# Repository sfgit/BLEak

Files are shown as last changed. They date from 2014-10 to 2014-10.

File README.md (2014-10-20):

BLEak
=====

BLE + ATMega Kit

Meet BLEak - the BLE + ATMega Kit.  This is a board I'm building for a one-day workshop in San Francisco.  The board includes the NRF8001 + ATMega328-AUR (SMD, a'la Arduino SMD) and should include some basic SPI sensors / IO.  Existing Arduino SW libraries for the nrf8001 should work with BLEak.  The basis of the workshop is to show the transition from Arduino to a production PCB and BLEak is a nice narrative that mixes some simple wireless / RF with the ATMega in a module that just might be the prodcut someone is trying to build.  

LICENSE + NOTES:  (PLEASE READ)
This design is released under a Creative-Commons Share-alike, Attribution license.  You can use this design without needing to ask for permission from me.

The designer (me, the guy typing this) is furnishing this item "as is". The design does not provide any warranty of the item whatsoever, whether express, implied, or statutory, including, but not limited to, any warranty of merchantability or fitness for a particular purpose or any warranty that the contents of the item will be error-free.

In no respect shall the designer incur any liability for any damages, including, but limited to, direct, indirect, special, or consequential damages arising out of, resulting from, or any way connected to the use of the item, whether or not based upon warranty, contract, tort, or otherwise; whether or not injury was sustained by persons or property or otherwise; and whether or not loss was sustained from, or arose out of, the results of, the item, or any services that may be provided by the designer.

Be careful.  This is a work in progress.  You use this AT YOUR OWN RISK.  Electronics such as these can kill.

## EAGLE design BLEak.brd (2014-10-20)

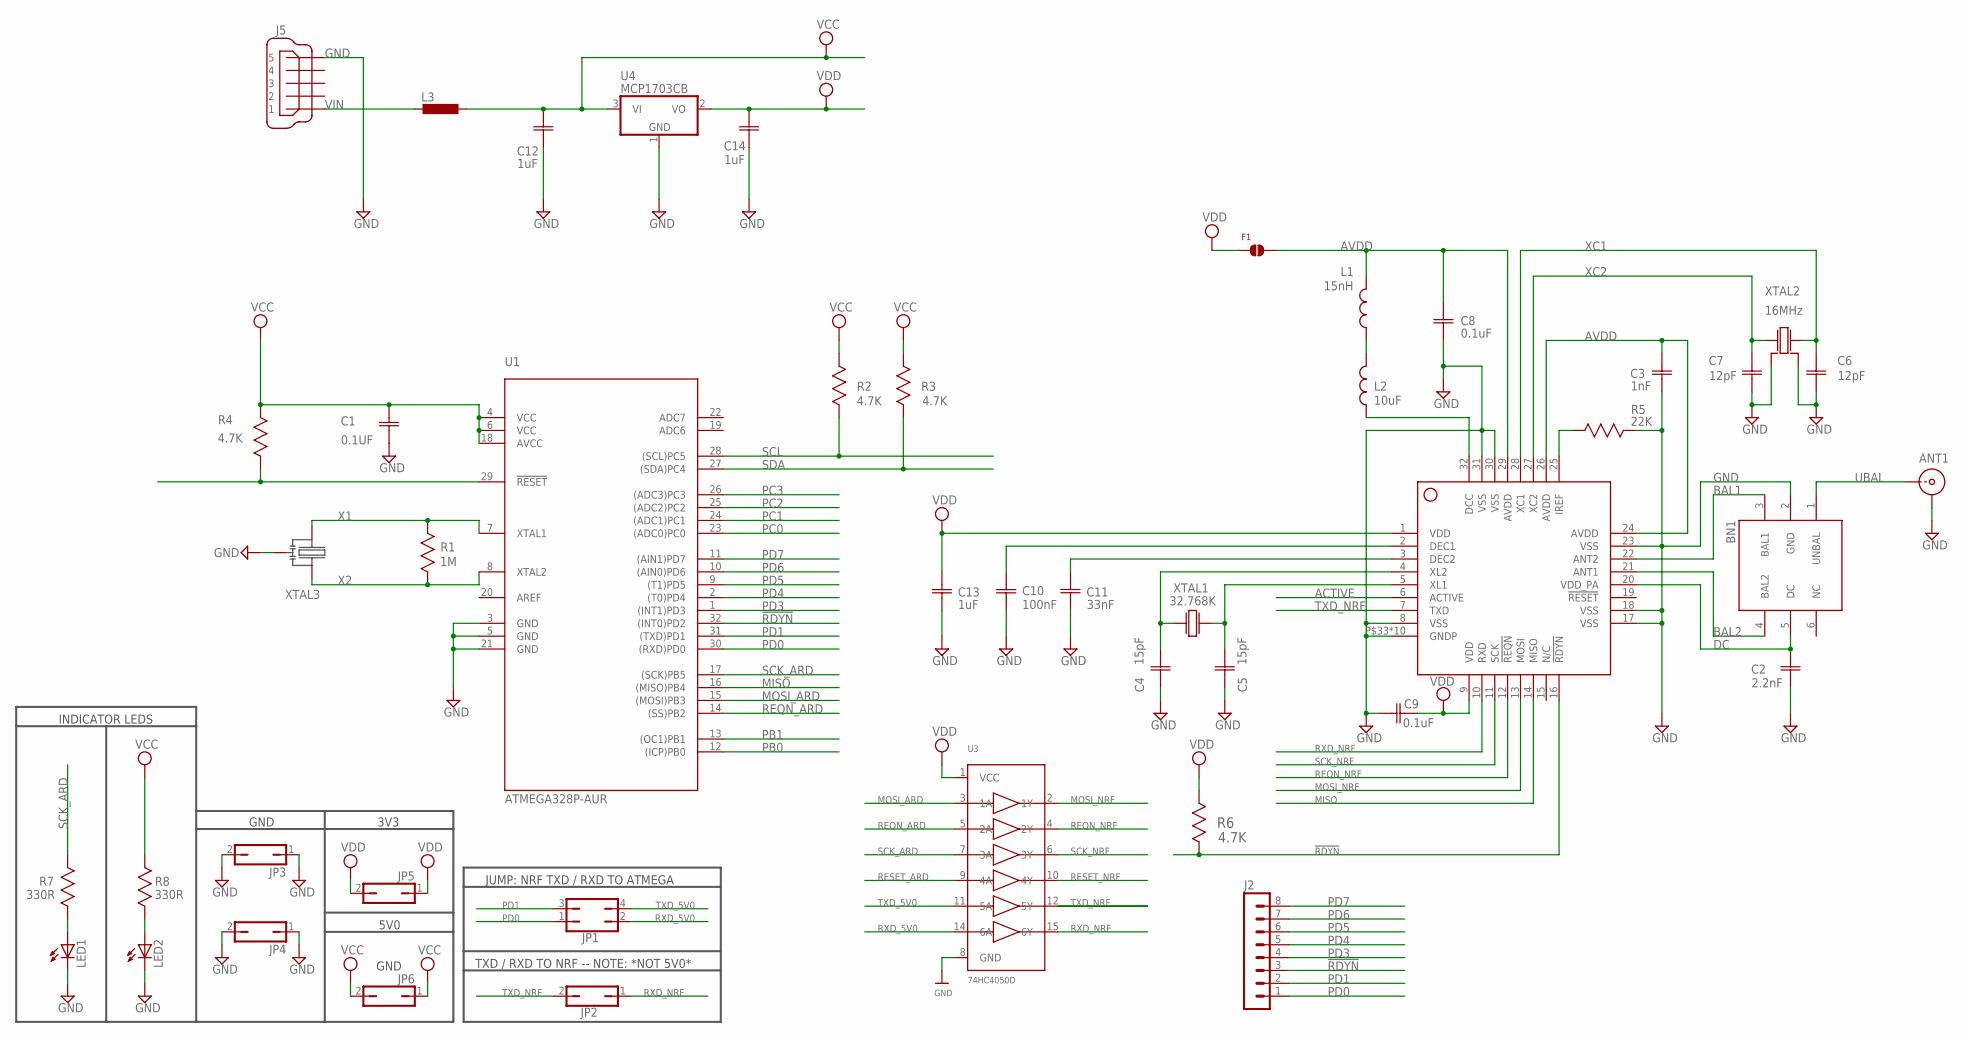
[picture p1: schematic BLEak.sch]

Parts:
ANT1: U.FL-R-SMT(01); U.FL; PARTNO U.FL-R-SMT(01)
BN1: 2450BM14A0002; BALUN; PARTNO 2450BM14A0002
C1: 0.1UF; CAPC1608X90N
C2: 2.2nF; CAPC1608X85N
C3: 1nF; CAPC1608X85N
C4, C5: 15pF; CAPC1608X85N
C6, C7: 12pF; CAPC1608X85N
C8, C9: 0.1uF; CAPC1608X90N
C10: 100nF; CAPC1608X90N
C11: 33nF; CAPC1608X85N
C12, C14: 1uF; CAPC2013X140N
C13: 1uF; CAPC1608X90N
F1: MMZ1608B121C; 0603
J2: MA08-1
J5: MINI-USB-UX60A-MB-5ST; UX60A-MB-5ST
JP1: JP2Q
JP2, JP3, JP4, JP5, JP6: JP1Q; JP1
L1: 15nH; 0402
L2: 10uF; 0603
L3: L-EUL1812; L1812
LED1, LED2: LEDCHIP-LED0603; CHIP-LED0603
R1: 1M; RESC1608X60N
R2, R3, R4, R6: 4.7K; RESC1608X60N
R5: 22K; RESC1608X60N
R7, R8: 330R; RESC1608X60N
U1: ATMEGA328P-AUR; TQFP-32; PARTNO ATMEGA328P-AUR
U2: NRF8001; QFN50P500X500X90-33N; PARTNO nRF8001
U3: 74HC4050D; TSSOP16
U4: MCP1703CB; SOT23
XTAL1: 32.768K; 3215
XTAL2: 16MHz; 3225
XTAL3: CSTCE16M0V53-R0

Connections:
!RDYN: J2.3, R6.2 (R2), U1.32 ((INT0)PD2), U2.16 (!RDYN)
ACTIVE: U2.6 (ACTIVE)
AVDD: C3.2 (C2), C8.2 (C2), F1.P$2 (2), L1.P$2, U2.24 (AVDD), U2.26 (AVDD), U2.29 (AVDD)
BAL1: BN1.3 (BAL1), U2.22 (ANT2)
BAL2: BN1.4 (BAL2), U2.21 (ANT1)
DC: BN1.5 (DC), C2.2 (C2), U2.20 (VDD_PA)
GND: ANT1.2, ANT1.3, BN1.2 (GND), C1.1 (C1), C2.1 (C1), C3.1 (C1), C4.1 (C1), C5.1 (C1), C6.1 (C1), C7.1 (C1), C8.1 (C1), C9.2 (C2), C10.1 (C1), C11.2 (C2), C12.1 (C1), C13.1 (C1), C14.1 (C1), J5.5, JP3.1, JP3.2, JP4.1, JP4.2, LED1.C, LED2.C, R5.1 (R1), U1.3 (GND), U1.5 (GND), U1.21 (GND), U2.8 (VSS), U2.17 (VSS), U2.18 (VSS), U2.23 (VSS), U2.30 (VSS), U2.31 (VSS), U2.P$33 (GNDP), U2.P$34 (GNDP), U2.P$35 (GNDP), U2.P$36 (GNDP), U2.P$37 (GNDP), U2.P$38 (GNDP), U2.P$39 (GNDP), U2.P$40 (GNDP), U2.P$41 (GNDP), U2.P$42 (GNDP), U3.8 (GND), U4.1 (GND), XTAL2.2, XTAL2.4, XTAL3.2
MISO: U1.16 ((MISO)PB4), U2.14 (MISO)
MOSI_ARD: U1.15 ((MOSI)PB3), U3.3 (1A)
MOSI_NRF: U2.13 (MOSI), U3.2 (1Y)
unnamed: R4.2 (R2), U1.29 (!RESET)
unnamed: R5.2 (R2), U2.25 (IREF)
unnamed: C4.2 (C2), U2.4 (XL2), XTAL1.2
unnamed: C5.2 (C2), U2.5 (XL1), XTAL1.1
unnamed: L1.P$1, L2.2
unnamed: L2.1, U2.32 (DCC)
unnamed: C11.1 (C1), U2.3 (DEC2)
unnamed: C10.2 (C2), U2.2 (DEC1)
unnamed: LED2.A, R8.2 (R2)
unnamed: LED1.A, R7.2 (R2)
PB0: U1.12 ((ICP)PB0)
PB1: U1.13 ((OC1)PB1)
PC0: U1.23 ((ADC0)PC0)
PC1: U1.24 ((ADC1)PC1)
PC2: U1.25 ((ADC2)PC2)
PC3: U1.26 ((ADC3)PC3)
PD0: J2.1, JP1.1, U1.30 ((RXD)PD0)
PD1: J2.2, JP1.3, U1.31 ((TXD)PD1)
PD3: J2.4, U1.1 ((INT1)PD3)
PD4: J2.5, U1.2 ((T0)PD4)
PD5: J2.6, U1.9 ((T1)PD5)
PD6: J2.7, U1.10 ((AIN0)PD6)
PD7: J2.8, U1.11 ((AIN1)PD7)
REQN_ARD: U3.5 (2A)
REQN_NRF: U2.12 (!REQN), U3.4 (2Y)
RESET_ARD: U3.9 (4A)
RESET_NRF: U3.10 (4Y)
RXD_5V0: JP1.2, U3.14 (6A)
RXD_NRF: JP2.1, U2.10 (RXD), U3.15 (6Y)
SCK_ARD: R7.1 (R1), U1.17 ((SCK)PB5), U3.7 (3A)
SCK_NRF: U2.11 (SCK), U3.6 (3Y)
SCL: R2.2 (R2), U1.28 ((SCL)PC5)
SDA: R3.2 (R2), U1.27 ((SDA)PC4)
TXD_5V0: JP1.4, U3.11 (5A)
TXD_NRF: JP2.2, U2.7 (TXD), U3.12 (5Y)
UBAL: ANT1.1, BN1.1 (UNBAL)
VCC: C1.2 (C2), C12.2 (C2), JP6.1, JP6.2, L3.1, R2.1 (R1), R3.1 (R1), R4.1 (R1), R8.1 (R1), U1.4 (VCC), U1.6 (VCC), U1.18 (AVCC), U4.3 (VI)
VDD: C9.1 (C1), C13.2 (C2), C14.2 (C2), F1.P$1 (1), JP5.1, JP5.2, R6.1 (R1), U2.1 (VDD), U2.9 (VDD), U3.1 (VCC), U4.2 (VO)
VIN: J5.1, L3.2
X1: R1.2 (R2), U1.7 (XTAL1), XTAL3.1
X2: R1.1 (R1), U1.8 (XTAL2), XTAL3.3
XC1: C6.2 (C2), U2.28 (XC1), XTAL2.3
XC2: C7.2 (C2), U2.27 (XC2), XTAL2.1

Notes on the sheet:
JUMP: NRF TXD / RXD TO ATMEGA
TXD / RXD TO NRF -- NOTE: *NOT 5V0*
GND
3V3
5V0
INDICATOR LEDS

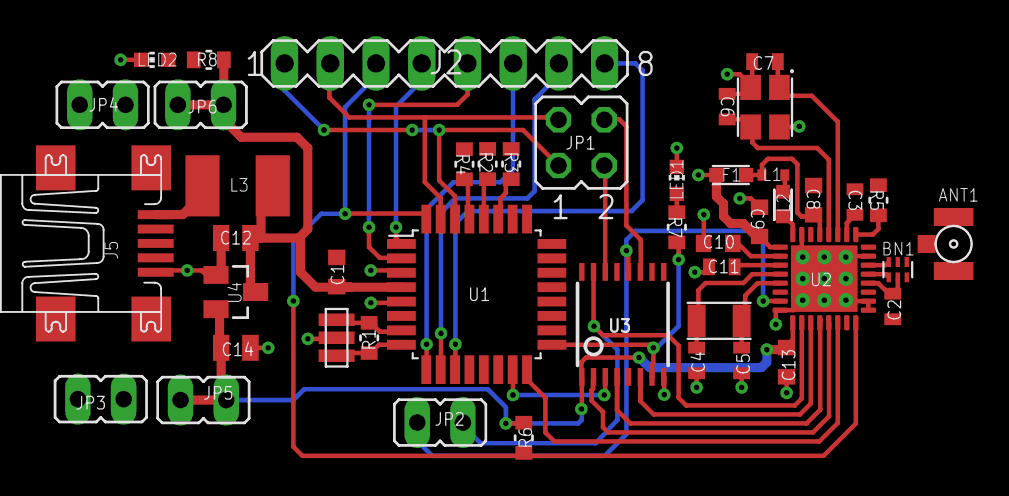
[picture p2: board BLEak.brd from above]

Board: 2 copper layers, 45 parts (0 on the bottom side), 43 nets.

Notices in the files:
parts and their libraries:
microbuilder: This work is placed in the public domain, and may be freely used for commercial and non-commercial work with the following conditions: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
